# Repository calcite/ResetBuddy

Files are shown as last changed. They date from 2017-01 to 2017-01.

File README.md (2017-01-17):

RESET BUDDY
==============
This device provides 9 relay outputs with a current rating up to 5A each. It can be fully powered and controlled by standard USB bus. Green LED mounted right next to corresponding relay indicates its state.

connector: 	USB mini type B
		Pluggable screw terminal AWG 16 - 26 

Board designed with KiCad 4.0.2

Box designed with freecad, based on HAMMOND 1455L1202

Controlling MCP2210:

Installation of lib_usb which in needed for running MCP2210
```
$apt-get update
$apt-get upgrade
$apt-get install python3-dev
$apt-get install cython3
$apt-get install libusb-1.0.0 libusb-1.0.0-dev libudev-dev
$pip3 install hidapi
```

Testing can be made with microchip utility: http://ww1.microchip.com/downloads/en/DeviceDoc/MCP2210Utility_v1.2.2.zip
Full control can be reached with utility attached to this project (RB utility).

RB utility control:
run python script with paramethers. Syntax is:
python RB_utility.py <operation><pin><state>[time]	parameter time is not obligatory

supported operations: 	
- set = s		– sets or clears pin (puts the pin into state 0 or 1)
- get = g	– reads state of pin
- reset = r	– sets pin for time (in seconds), then clears it
- rev_reset = rev – opposite of reset
- clearall = c	- clears all pins
- test = t	- visual test
- crazy! 		- even better test

For some operations there is no need for all other parameters but you always have to put them in (poor programming skills). 

allowed pin inputs: 1,2,3,4,5,6,7,8,9,all,a,x	(a = all, x for operations without pin input)

allowed state iputs: 0,1,x			(x for operations without state input)

time parameter only for reset operation. You must put –t ahead of the parameter itself

examples:
```
python RB_utility.py set 1 1	//sets pin 1 into logic 1
python RB_utility.py r 9 x –t 1	//sets pin 9 for 1 second, then clears it 
python RB_utility.py crazy! x x 	//just try it ;) 
```

love is all around us

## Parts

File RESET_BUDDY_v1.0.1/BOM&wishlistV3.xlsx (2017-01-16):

BOM & WISHLIST - USB relay switch
 | description | Part number | ordering code | package | price/piece | pieces | total price | link
IC1 | USB to SPI protocol converter | MCP2210-I/SO | 2078574 | SOIC-20 | 56.59 Kč | 1 | 56.59 Kč | http://cz.farnell.com/microchip/mcp2210-i-so/ic-usb-to-spi-converter-20soic/dp/2078574
U1 | rezonátor 12Mhz | CSTCE12M0G55Z-R0 | 2470357 | ??? | 6.32 Kč | 5 | 31.61 Kč | http://cz.farnell.com/murata/cstce12m0g55z-r0/resonator-ceramic-12mhz-smd/dp/2470357
R5 | resistor 390 | MC01W08051390R | 9333150 | 0805 | 0.055 | 10 | 0.55 Kč | http://cz.farnell.com/multicomp/mc01w08051390r/res-thick-film-390r-1-0-1w-0805/dp/9333150
C2 | capacitor 0,1uF | 0805B104K500CT | 2496944RL | 0805 | 0.409 | 10 | 4.09 Kč | http://cz.farnell.com/walsin/0805b104k500ct/capacitor-mlcc-x7r-0-1uf-50v-0805/dp/2496944RL
C3 | capacitor 1uF | 0805F105Z250CT | 2496996 | 0805 | 0.82 | 10 | 8.20 Kč | http://cz.farnell.com/walsin/0805f105z250ct/capacitor-mlcc-y5v-1uf-25v-0805/dp/2496996
P1 | USB mini B connector | 67503-1020 | 1125348 |  | 21.06 Kč | 1 | 21.06 Kč | http://cz.farnell.com/molex/67503-1020/mini-usb-2-0-otg-type-b-rcpt-smt/dp/1125348
L1, L2 | Ferite bead 220ohm | BLM18KG221SN1D | 1781090 | 0603 | 1.42 Kč | 10 | 14.22 Kč | http://cz.farnell.com/murata/blm18kg221sn1d/ferrite-bead-0603-220r-2-2a/dp/1781090
R1 | resistor 1M | MC01W080511M | 9332413 | 0805 | 0.06 Kč | 10 | 0.55 Kč | http://cz.farnell.com/multicomp/mc01w080511m/res-thick-film-1m-1-0-1w-0805/dp/9332413
C1 | capacitor 4,7nF | 0805B472K500CT | 2496980 | 0805 | 0.48 Kč | 10 | 4.80 Kč | http://cz.farnell.com/walsin/0805b472k500ct/capacitor-mlcc-x7r-4700pf-50v/dp/2496980
REL1,REL2,REL3,REL4 | Relay 5V (coil) 220V, 5A | IM03DGR | 1629011 | weird one | 58.80 Kč | 4 | 235.21 Kč | http://cz.farnell.com/te-connectivity/im03dgr/relay-signal-dpdt-250vac-220vdc/dp/1629011
Q1, Q2, Q3, Q4 | N-MOSFET 0,8V Vgs | NTR4003NT3G | 2101820 | SOT-23 | 1.76 Kč | 20 | 35.18 Kč | http://cz.farnell.com/on-semiconductor/ntr4003nt3g/mosfet-n-ch-30v-0-56a-sot-23/dp/2101820
D2, D5, D6, D8 | Standart diode (relay protection) | S1FLD-GS08 | 1779224 | DO219ab | 2.63 Kč | 10 | 26.34 Kč | http://cz.farnell.com/vishay/s1fld-gs08/diode-switching-200v-0-7a-smf/dp/1779224
R4,R8,R11,R14 | resistor 560 ohm | MC01W08051560R | 9333363RL | 0805 | 0.05 Kč | 20 | 1.04 Kč | http://cz.farnell.com/multicomp/mc01w08051560r/res-thick-film-560r-1-0-1w-0805/dp/9333363RL
R1, R6, R9, R12 | resistor 56 kohm | MC01W0805156K | 9333380 | 0805 | 0.05 Kč | 20 | 1.04 Kč | http://cz.farnell.com/multicomp/mc01w0805156k/res-thick-film-56k-1-0-1w-0805/dp/9333380
P2,P3,P4,P5 | pluggable terminal block female | CTB932HD/2 | 2493677 | 3.5mm | 3.09 Kč | 10 | 30.92 Kč | http://cz.farnell.com/camdenboss/ctb932hd-2/terminal-block-header-2pos-th/dp/2493677
--- | pluggable terminal block male | CTB922HD/2 | 2493646 | 3.5mm | 8.92 Kč | 10 | 89.17 Kč | http://cz.farnell.com/camdenboss/ctb922hd-2/terminal-block-pluggable-2pos/dp/2493646
D1, D3, D4, D7 | THT LED | L-934SGC | 1142523 | 3mm | 3.92 Kč | 10 | 39.20 Kč | http://cz.farnell.com/kingbright/l-934sgc/led-3mm-green-150mcd-568nm/dp/1142523
R2, R7, R10, R13 | rezistor 150 ohm | MC01W08051150R | 9332596 | 0805 | 0.06 Kč | 10 | 0.55 Kč | http://cz.farnell.com/multicomp/mc01w08051150r/res-thick-film-150r-1-0-1w-0805/dp/9332596
 |  |  |  |  |  |  | 600.33 Kč

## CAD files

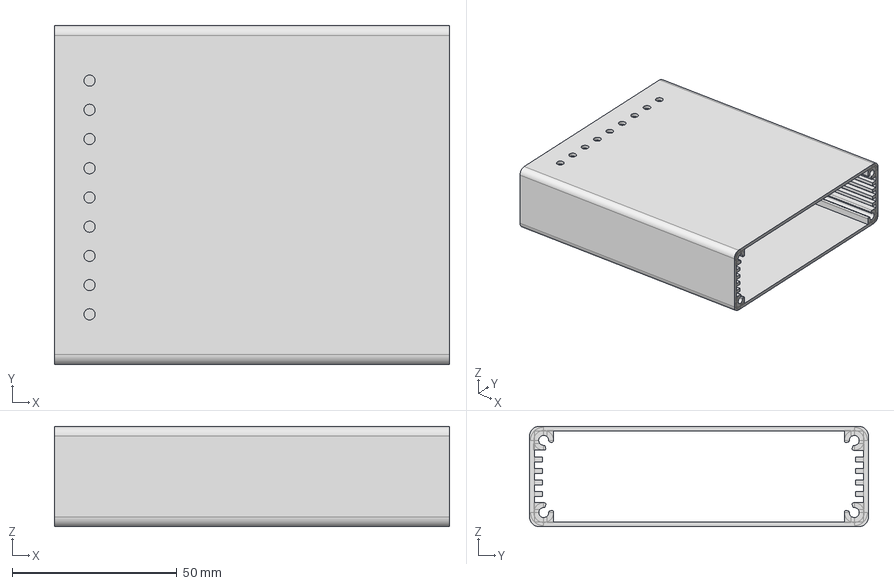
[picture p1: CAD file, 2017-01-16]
freecad_model/RESET_BUDDY_krabicka2.FCStd
120.0 x 103.0 x 30.5 mm

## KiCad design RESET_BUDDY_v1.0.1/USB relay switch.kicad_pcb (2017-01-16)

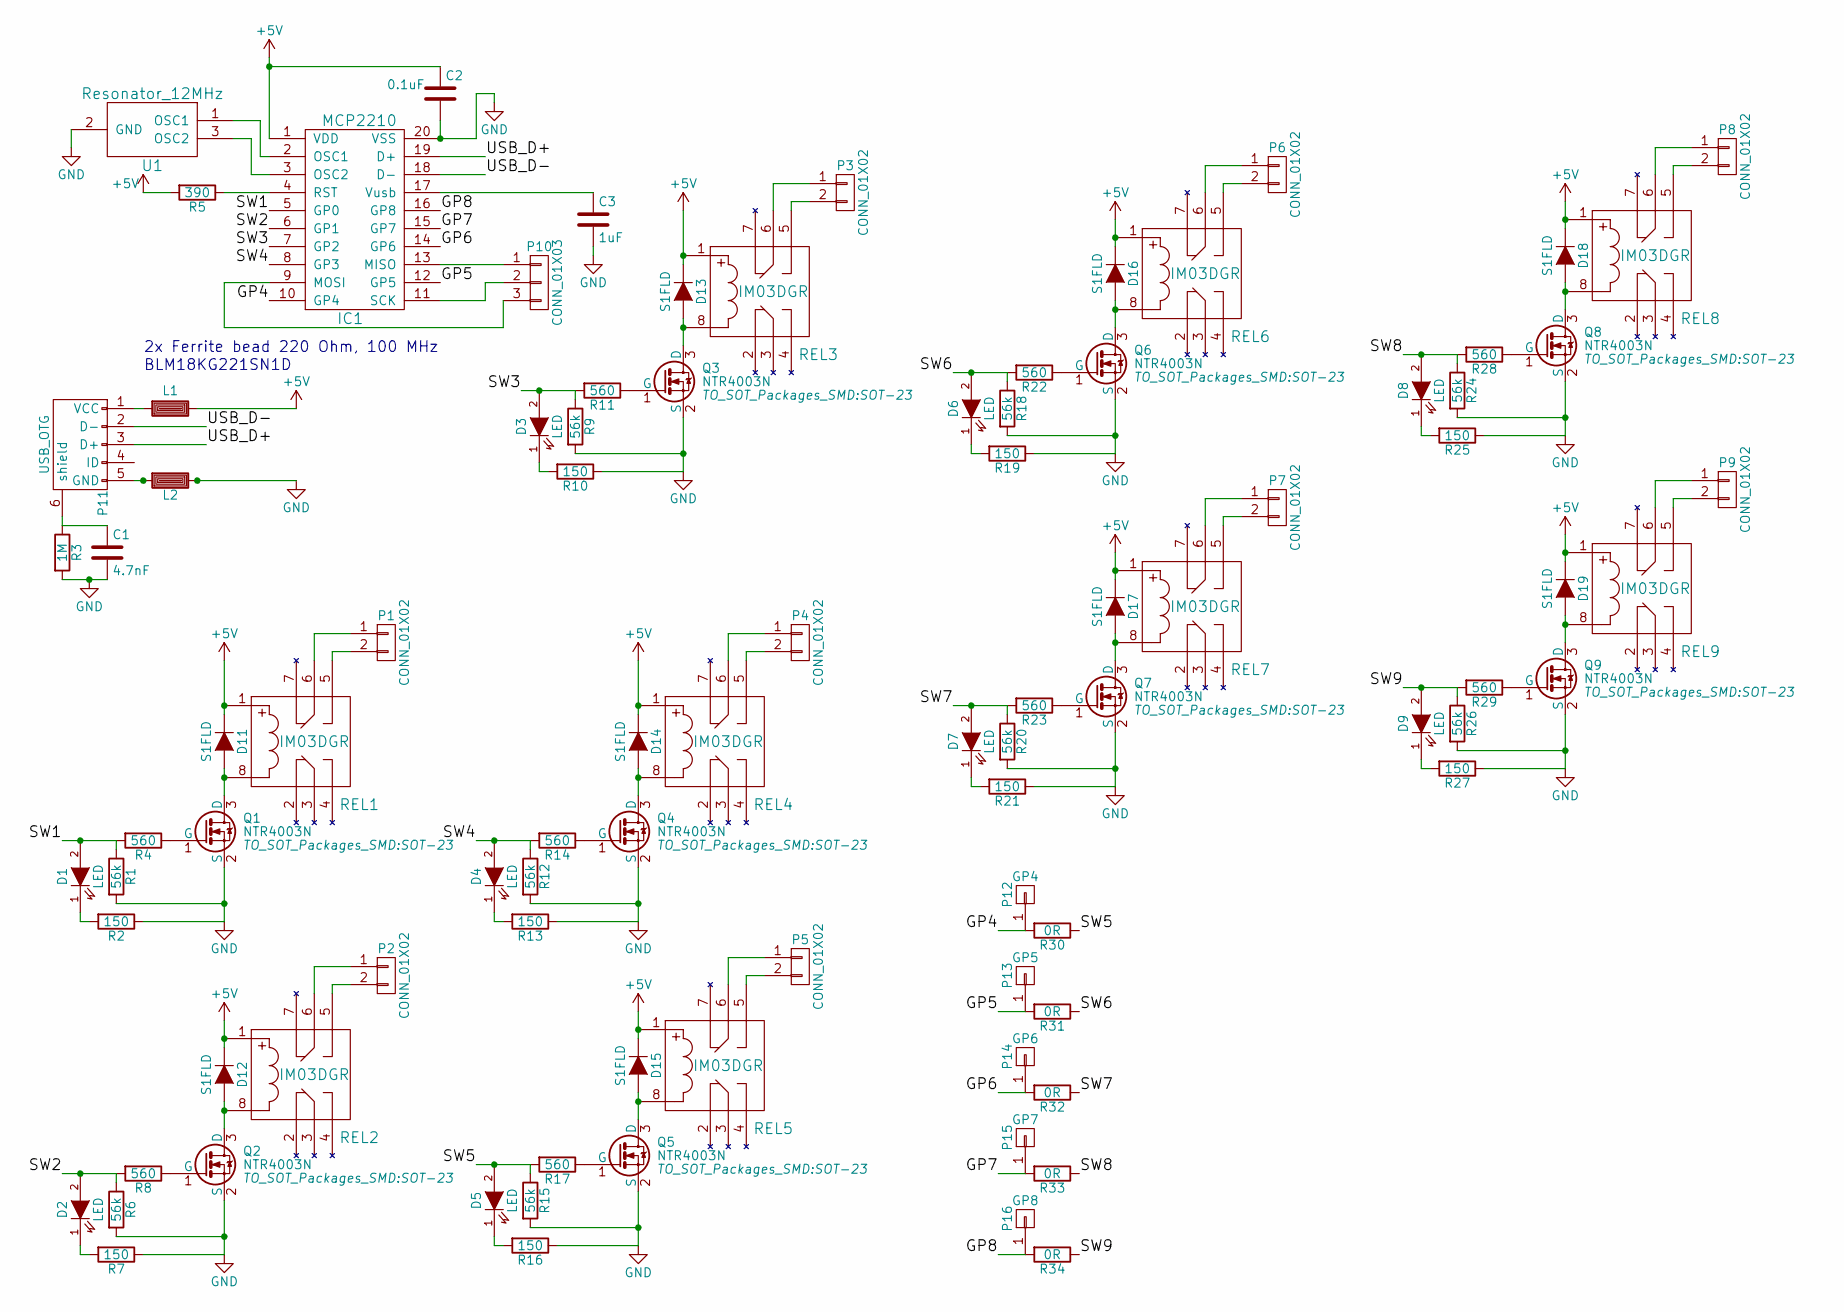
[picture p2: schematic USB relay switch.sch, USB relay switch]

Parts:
C1: 4.7nF; C_0805_HandSoldering
C2: 0.1uF; C_0805_HandSoldering
C3: 1uF; C_0805_HandSoldering
D1, D2, D3, D4, D5, D6, D7, D8, D9: LED; LED-3MM
D11, D12, D13, D14, D15, D16, D17, D18, D19: S1FLD; DO-219AB_SMF
IC1: MCP2210; SOIC-20_7.5x12.8mm_Pitch1.27mm
L1, L2: FER; R_0603_HandSoldering
P1, P2, P3, P4, P5, P6, P7, P8, P9: CONN_01X02; CTB932HD2
P10: CONN_01X03; Pin_Header_Straight_1x03
P11: USB_OTG; USB_Mini-B
P12: GP4; Pin_Header_Straight_1x01
P13: GP5; Pin_Header_Straight_1x01
P14: GP6; Pin_Header_Straight_1x01
P15: GP7; Pin_Header_Straight_1x01
P16: GP8; Pin_Header_Straight_1x01
Q1, Q2, Q3, Q4, Q5, Q6, Q7, Q8, Q9: NTR4003N; SOT-23
R1, R6, R9, R12, R15, R18, R20, R24, R26: 56k; R_0805_HandSoldering
R2, R7, R10, R13, R16, R19, R21, R25, R27: 150; R_0805_HandSoldering
R3: 1M; R_0805_HandSoldering
R4, R8, R11, R14, R17, R22, R23, R28, R29: 560; R_0805_HandSoldering
R5: 390; R_0805_HandSoldering
R30, R31, R32, R33, R34: 0R; R_0805_HandSoldering
REL1, REL2, REL3, REL4, REL5, REL6, REL7, REL8, REL9: IM03DGR
U1: Resonator_12MHz; rezonator_murrata

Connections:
+5V: C2.1, D11.1 (K), D12.1 (K), D13.1 (K), D14.1 (K), D15.1 (K), D16.1 (K), D17.1 (K), D18.1 (K), D19.1 (K), IC1.1 (VDD), L1.1, R5.2, REL1.1, REL2.1, REL3.1, REL4.1, REL5.1, REL6.1, REL7.1, REL8.1, REL9.1
/GP4: IC1.10 (GP4), P12.1, R30.2
/GP5: IC1.12 (GP5), P13.1, R31.2
/GP6: IC1.14 (GP6), P14.1, R32.2
/GP7: IC1.15 (GP7), P15.1, R33.2
/GP8: IC1.16 (GP8), P16.1, R34.2
/SW1: D1.2 (A), IC1.5 (GP0), R1.1, R4.2
/SW2: D2.2 (A), IC1.6 (GP1), R6.1, R8.2
/SW3: D3.2 (A), IC1.7 (GP2), R9.1, R11.2
/SW4: D4.2 (A), IC1.8 (GP3), R12.1, R14.2
/SW5: D5.2 (A), R15.1, R17.2, R30.1
/SW6: D6.2 (A), R18.1, R22.2, R31.1
/SW7: D7.2 (A), R20.1, R23.2, R32.1
/SW8: D8.2 (A), R24.1, R28.2, R33.1
/SW9: D9.2 (A), R26.1, R29.2, R34.1
/USB_D+: IC1.19 (D+), P11.3 (D+)
/USB_D-: IC1.18 (D-), P11.2 (D-)
GND: C1.2, C2.2, C3.2, IC1.20 (VSS), L2.1, Q1.2 (S), Q2.2 (S), Q3.2 (S), Q4.2 (S), Q5.2 (S), Q6.2 (S), Q7.2 (S), Q8.2 (S), Q9.2 (S), R1.2, R2.1, R3.2, R6.2, R7.1, R9.2, R10.1, R12.2, R13.1, R15.2, R16.1, R18.2, R19.1, R20.2, R21.1, R24.2, R25.1, R26.2, R27.1, U1.2 (GND)
unnamed: C1.1, P11.6 (shield), R3.1
unnamed: C3.1, IC1.17 (Vusb)
unnamed: D1.1 (K), R2.2
unnamed: D2.1 (K), R7.2
unnamed: D3.1 (K), R10.2
unnamed: D4.1 (K), R13.2
unnamed: D5.1 (K), R16.2
unnamed: D6.1 (K), R19.2
unnamed: D7.1 (K), R21.2
unnamed: D8.1 (K), R25.2
unnamed: D9.1 (K), R27.2
unnamed: D11.2 (A), Q1.3 (D), REL1.8
unnamed: D12.2 (A), Q2.3 (D), REL2.8
unnamed: D13.2 (A), Q3.3 (D), REL3.8
unnamed: D14.2 (A), Q4.3 (D), REL4.8
unnamed: D15.2 (A), Q5.3 (D), REL5.8
unnamed: D16.2 (A), Q6.3 (D), REL6.8
unnamed: D17.2 (A), Q7.3 (D), REL7.8
unnamed: D18.2 (A), Q8.3 (D), REL8.8
unnamed: D19.2 (A), Q9.3 (D), REL9.8
unnamed: IC1.2 (OSC1), U1.1 (OSC1)
unnamed: IC1.3 (OSC2), U1.3 (OSC2)
unnamed: IC1.4 (RST), R5.1
unnamed: IC1.9 (MOSI), P10.3
unnamed: IC1.11 (SCK), P10.2
unnamed: IC1.13 (MISO), P10.1
unnamed: L1.2, P11.1 (VCC)
unnamed: L2.2, P11.5 (GND)
unnamed: P1.1, REL1.6
unnamed: P1.2, REL1.5
unnamed: P2.1, REL2.6
unnamed: P2.2, REL2.5
unnamed: P3.1, REL3.6
unnamed: P3.2, REL3.5
unnamed: P4.1, REL4.6
unnamed: P4.2, REL4.5
unnamed: P5.1, REL5.6
unnamed: P5.2, REL5.5
unnamed: P6.1, REL6.6
unnamed: P6.2, REL6.5
unnamed: P7.1, REL7.6
unnamed: P7.2, REL7.5
unnamed: P8.1, REL8.6
unnamed: P8.2, REL8.5
unnamed: P9.1, REL9.6
unnamed: P9.2, REL9.5
unnamed: Q1.1 (G), R4.1
unnamed: Q2.1 (G), R8.1
unnamed: Q3.1 (G), R11.1
unnamed: Q4.1 (G), R14.1
unnamed: Q5.1 (G), R17.1
unnamed: Q6.1 (G), R22.1
unnamed: Q7.1 (G), R23.1
unnamed: Q8.1 (G), R28.1
unnamed: Q9.1 (G), R29.1

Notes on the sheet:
2x Ferrite bead 220 Ohm, 100 MHz
BLM18KG221SN1D

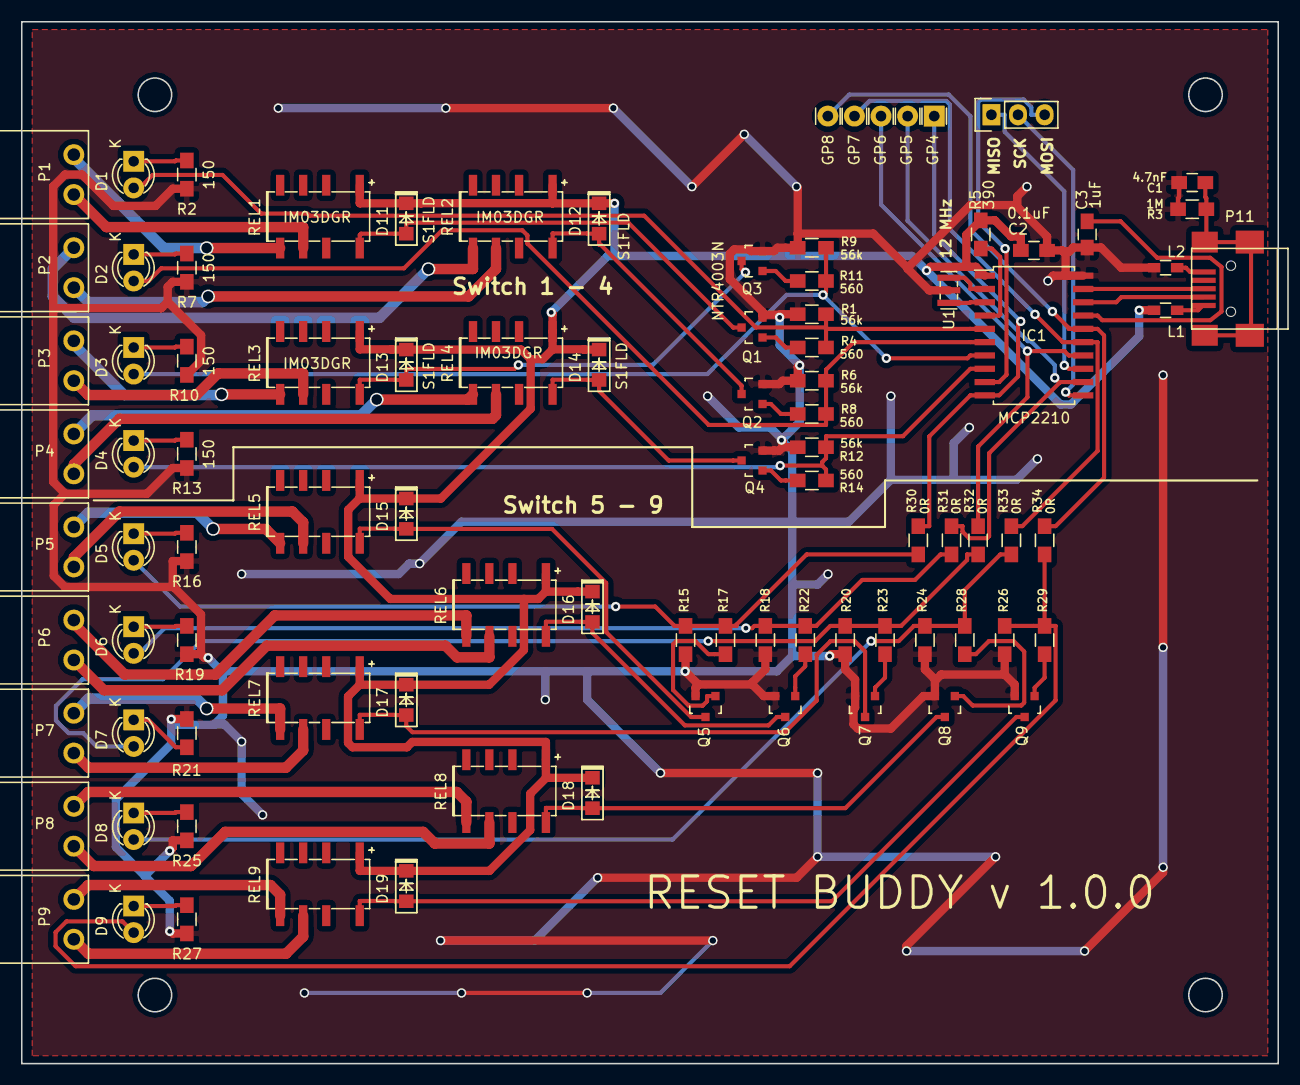
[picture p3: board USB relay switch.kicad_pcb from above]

Board: 2 copper layers, 120.0 x 99.5 mm, 93 parts (0 on the bottom side), 73 nets.

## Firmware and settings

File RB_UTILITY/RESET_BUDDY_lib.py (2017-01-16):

# -*- coding: utf-8 -*-
"""
Created on Thu May 12 10:20:54 2016

@author: ALCZ11511047
"""

from mcp2210 import MCP2210
import time

class RBUDDY(object): 
    def __init__(self):
        """inicialization of MCP2210 main chip which allow communication from system to display"""
        VID = 0x04D8
        PID = 0x00DE
        
        #self.communication = MCP2210(0x04D8, 0x00DE)
        try:
            self.communication = MCP2210(VID,PID)
        except Exception as e:
            print (e)
            raise Exception('Failed to open USB chanel')

        #gpio local variables
        self._gpio = self.communication.gpio
        self._gpio_direction = self.communication.gpio_direction
        
        """
        GPIO designations 	- 0x00 is GPIO, 0x01 is Chip selects, 0x02 is Dedicated function pin
        GPIO direction 		- 0x00 is Output, 0x01 is Input
        """
        #pins set as GPIO 
        self.communication.gpio_direction.pin_designations = [0] * 9
        #pins set as output           
        self.communication.gpio_direction = [0] * 9
        #clear pins
        self.communication.gpio = [0] * 9  
         
        
    def set_pin(self, pin, value):
        """Sets or clears GPIO"""
        self._gpio[pin-1] = value
        print ('pin ' + repr(pin) + ' set to ' + repr(value))
        
    def get_pin(self, pin):
        """returns value of a GPIO""" 
        value = self._gpio[pin-1]
        print ('pin ' + repr(pin) + ' is set to ' + repr(value))
        return self._gpio[pin-1]
        
    def reset_pin(self,pin,seconds):
        """sets and clears pin after selected time in seconds (reset)"""
        print ('reset pin ' + repr(pin) + ' for ' + repr(seconds) + ' second(s)')
        self._gpio[pin-1] = 1
        time.sleep(seconds)
        self._gpio[pin-1] = 0
        
    def reverse_reset_pin(self,pin,seconds):
        """ clears and sets pin after selected time in seconds (reverse reset)"""
        print ('reverse reset pin ' + repr(pin) + ' for ' + repr(seconds) + ' second(s)')
        self._gpio[pin-1] = 0
        time.sleep(seconds)
        self._gpio[pin-1] = 1    
          
    def clear_all(self):
        """clears all GPIOs"""
        for i in range (9):
            self._gpio[i] = 0
        print ('ALL CLEARED!') 
        
    def test(self):
        """all pin visual test"""
        for i in range (9):
            time.sleep(0.25)
            self._gpio[i] = 1
            time.sleep(0.25)
            self._gpio[i] = 0   
        print ('TEST COMPLETED')     
        
    def crazy(self):
        """all pin visual test"""
        for j in range (30):
            for i in range (9):
                time.sleep(0.002)
                self._gpio[i] = 1
                time.sleep(0.002)
                self._gpio[i] = 0 
        for j in range (10):
            for i in range (9):
                time.sleep(0.01)
                self._gpio[i] = 1
                time.sleep(0.01)
                self._gpio[i] = 0              
                
        print ('TEST COMPLETED')     
       

"""   USAGE EXAMPLE  
     
USER = RBUDDY()

USER.set_pin(3,1)
time.sleep(0.5)

USER.get_pin(2)
time.sleep(0.5)

USER.set_pin(2,1)
time.sleep(0.5)

USER.clear_all()
time.sleep(0.5)

USER.reset_pin(2,0.1)


"""

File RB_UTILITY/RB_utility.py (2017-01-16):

# -*- coding: utf-8 -*-
"""
Created on Thu May 12 16:32:03 2016

@author: ALCZ11511047
"""

import argparse
from RESET_BUDDY_lib import RBUDDY

# argparse cause pzthon script to be run with parameters.
# this script has 3 parameters  - operation (set, get, reset...)
#                               - pin 
#                               - state (low/high - 0/1)
#                               - optional - time (reset speed)

# resulting script run syntax:
# python RB_utility.py operation pin state (time)  


parser = argparse.ArgumentParser()
parser.add_argument("operation", help="Choose action (set,reset,clear all",
                    type = str, choices = ["set","get","reset","rev_reset","clearall",
                    "test","s","g","r","rev","c","t",'crazy!'])
parser.add_argument("pin", choices = ['x','a','all','1','2','3','4','5','6','7','8','9'],
                    help = "choose pin")
parser.add_argument("state", choices = ['x','0','1'],
                    help = "choose state")  
parser.add_argument("-t","--time", type = float, help = "reset time in seconds") 
            
args = parser.parse_args()            



UTILITY = RBUDDY()

#sets or clears 1 pin or all pins
if args.operation == "set" or args.operation == "s":
    if (args.pin == 'x') or (args.state == 'x') :
        print('invalid input!!!')
    elif args.pin == 'a':
        for i in range (9):
            UTILITY.set_pin((i+1),int(args.state))
    elif args.pin == 'all':
        for i in range (9):
            UTILITY.set_pin((i+1),int(args.state))        
    else:  
        UTILITY.set_pin(int(args.pin),int(args.state))      

        
if args.operation == "get" or args.operation == "g":
    if args.pin == 'x':
        print('invalid input!!!')
    elif args.pin == 'a':
        for i in range (9):   
            UTILITY.get_pin(i+1)
    elif args.pin == 'all':
        for i in range (9):   
            UTILITY.get_pin(i+1)        
    else:
        UTILITY.get_pin(int(args.pin))
            
if args.operation == "reset" or args.operation == "r":
    if args.time == None:
        args.time = 1
    if args.pin == 'x':
        print('invalid input!!!')
    elif args.pin == 'a':
        for i in range (9): 
            UTILITY.reset_pin(i+1, args.time)
    elif args.pin == 'all':
        for i in range (9):   
            UTILITY.reset_pin(i+1, args.time)        
    else:         
        UTILITY.reset_pin(int(args.pin), args.time)
    
if args.operation == "rev_reset" or args.operation == "rev":
    if args.time == None:
        args.time = 1
    if args.pin == 'x':
        print('invalid input!!!')
    elif args.pin == 'a':
        for i in range (9): 
            UTILITY.reverse_reset_pin(i+1, args.time)
    elif args.pin == 'all':
        for i in range (9):   
            UTILITY.reverse_reset_pin(i+1, args.time)        
    else:         
        UTILITY.reverse_reset_pin(int(args.pin), args.time)
    
        
if args.operation == "crazy!":
    UTILITY.crazy()      

if args.operation == "test"or args.operation == "t":
    UTILITY.test()         
    
               

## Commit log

2017-01-16 RESET BUDDY reached internet!
    [BOM&wishlistV3.xlsx, RESET BUDDY krabicka.FCStd, RESET BUDDY krabicka2.FCStd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]
2017-01-16 Until now it was just a game. Now we have a serious project here.
    [BOM&wishlistV3.xlsx, RESET BUDDY krabicka.FCStd, RESET BUDDY krabicka2.FCStd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]
2017-01-16 folder repair
    [BOM&wishlistV3.xlsx, RESET_BUDDY_krabicka2.FCStd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]
2017-01-17 deleting old version
    [BOM&wishlistV3.xlsx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]
